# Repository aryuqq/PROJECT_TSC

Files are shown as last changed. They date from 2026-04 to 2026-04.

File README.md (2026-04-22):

# InkTime v6 - Advanced Open Source Smartwatch

InkTime v6 este un smartwatch open-source de inalta performanta, axat pe eficienta energetica extrema si un factor de forma compact. Aceasta revizie hardware aduce imbunatatiri majore pe partea de management al energiei, feedback haptic avansat si generarea tensiunilor pentru display direct pe placa de baza.

Acest repository contine fisierele de design hardware (Schematice, PCB layout, BOM) pentru faza **EVT (Engineering Validation Test)** a versiunii 6.

## 1. Diagrama Bloc a Sistemului

```mermaid
graph TD
    %% Power Management
    USB[Conector USB-C / ESD] -->|5V| CHG[IC Incarcare BQ25180]
    CHG --> BATT[Acumulator LiPo 3.7V]
    BATT --> FG[Fuel Gauge MAX17048]
    BATT --> DCDC[Buck-Boost RT6160]
    
    %% Core Power
    DCDC -.->|3.3V Stabilizat| MCU[SoC nRF52840]
    DCDC -.->|3.3V| PERIPH[Periferice]
    
    %% Core & Connectivity
    MCU <-->|I2C| FG
    
    %% Interfaces & Peripherals
    MCU <-->|SPI + Control| EINK[Display E-Paper 1.54]
    MCU -->|PWM/Control| EINK_DRV[Circuit E-Paper Drive On-Board]
    MCU <-->|I2C + INT| IMU[Accelerometru BMA423]
    MCU <-->|I2C + EN| HAPTIC[Driver Haptic DRV2605]
    HAPTIC --> VIB[Motor LRA/ERM]
    MCU -->|GPIO| BTN[3x Butoane Navigare]
```

## 2. Bill Of Materials (BOM)

Tabelul de mai jos contine circuitele integrate (IC-urile) principale folosite in designul placii. Lista completa se gaseste in fisierul .csv din folderul Manufacturing.
| Componenta | Rol in sistem | JLC Part # | Link Datasheet |
| :--- | :--- | :--- | :--- |
| **nRF52840-QIAA** | Microcontroller principal (BLE, Cortex-M4F) | C206001 | [Datasheet nRF52840](https://infocenter.nordicsemi.com/pdf/nRF52840_PS_v1.7.pdf) |
| **BQ25180YBGR** | IC Incarcare liniara avansata (Ultra-Low Iq) | N/A | [Datasheet BQ25180](https://www.ti.com/lit/ds/symlink/bq25180.pdf) |
| **RT6160AWSC** | Regulator DC/DC Buck-Boost 3.3V | C2836254 | [Datasheet RT6160](https://www.richtek.com/assets/product_file/RT6160A/DS6160A-02.pdf) |
| **MAX17048G+T10** | Fuel Gauge (Monitorizare Baterie prin I2C) | C113374 | [Datasheet MAX17048](https://www.analog.com/media/en/technical-documentation/data-sheets/MAX17048-MAX17049.pdf) |
| **BMA423** | Accelerometru Ultra-Low Power (Pedometer HW) | C283084 | [Datasheet BMA423](https://www.bosch-sensortec.com/media/boschsensortec/downloads/datasheets/bst-bma423-ds004.pdf) |
| **DRV2605YZFR** | Driver Haptic I2C (Generare vibratii complexe) | C63435 | [Datasheet DRV2605](https://www.ti.com/lit/ds/symlink/drv2605.pdf) |
| **USBLC6-2SC6Y** | Protectie ESD pe liniile de date si alimentare USB-C | C7519 | [Datasheet USBLC6](https://www.st.com/resource/en/datasheet/usblc6-2.pdf) |

## 3. Descrierea Functionalitatii Hardware
### Procesare si Conectivitate:

Inima ceasului InkTime este SoC-ul Nordic nRF52840. A fost ales datorita suportului nativ pentru Bluetooth 5.0 (BLE), esential pentru sincronizarea notificarilor cu telefonul mobil. Arhitectura ARM Cortex-M4F permite procesarea eficienta a algoritmilor senzorilor.
Managementul Consumului de Energie (Power Tree):

Fiind un dispozitiv wearable, constrangerile de baterie sunt critice. Sistemul energetic a fost complet reproiectat in v6.

Sistemul este alimentat de o baterie LiPo de mici dimensiuni (ex. 500mAh). Monitorizarea starii de incarcare (SoC) se face precis si fara consum mare de curent prin cipul MAX17048.

Incarcarea se face la 5V printr-un circuit BQ25180, un cip de top care permite controlul precis al pragurilor de incarcare.

Pentru a asigura tensiunea de 3.3V am folosit un convertor Buck-Boost RT6160 in loc de un LDO simplu. Acesta mentine 3.3V perfect stabil chiar si cand tensiunea bateriei scade, extragand maximum de energie din acumulator inainte de oprire.

### Periferice si Interfete:

Display-ul E-Ink: Comunica prin protocol SPI. Fata de versiunile anterioare, placa include propriul circuit de generare a tensiunilor inalte (E-Paper Drive On-Board cu inductor si mosfet), ceea ce reduce grosimea totala. Consuma 0mA pentru a mentine imaginea afisata.

Senzorii (IMU, Haptic, Fuel Gauge): Comunicatia se realizeaza pe o magistrala I2C partajata. BMA423 are un mod special de "step counter" hardware care poate trezi microcontroller-ul din sleep doar cand utilizatorul face un pas. Driver-ul DRV2605 ofera feedback haptic premium, descarcand procesorul de generarea semnalelor PWM.

## 4. Alocarea Pinilor nRF52840

Microcontroller-ul nRF52840 permite maparea flexibila a pinilor (orice functie digitala pe orice pin), lucru care a facilitat o rutare curata pe PCB.

| Pin nRF52840 | Nume Net / Functie | Justificare / Detalii |
| :--- | :--- | :--- |
| **P0.26 / P0.27** | `SDA/2.4C`, `SCL/2.4C` | Magistrala I2C principala (IMU, Haptic, Fuel Gauge, Charger). Contine rezistente de pull-up. |
| **P0.08 / P1.09** | `IMU_INT1`, `IMU_INT2` | Pini de intrerupere hardware. BMA423 trimite semnale aici pentru a trezi SoC-ul cand detecteaza miscare. |
| **P0.12** | `HAPTIC_EN` | Pin configurat ca iesire pentru a activa/dezactiva driver-ul de vibratii DRV2605. |
| **P0.04** | `EPD_CS` | Chip Select pentru activarea magistralei SPI a display-ului E-Paper. |
| **P0.13 - P0.15** | `MOSI`, `MISO`, `SCK` | Magistrala SPI hardware (rutata direct catre conectorul FPC de 24 pini). |
| **Diverse** | `SW_UP`, `SW_ENT`, `SW_DN` | Pini conectati la butoanele laterale, configurati cu retele RC (Hardware Debouncing) pentru o citire curata. |

## 5. Design Log & Integrare Mecanica
### Constructia PCB-ului:

Layout-ul este extrem de dens, folosind componente in capsule miniaturale (BGA si QFN). Rutarea respecta zona de "Keepout" a antenei de 2.4GHz, asigurand o bataie maxima a semnalului Bluetooth.
Interfete Fizice:

Conectorul USB Type-C este utilizat exclusiv pentru incarcare (5V) si a fost ranforsat mecanic. Debug-ul se face prin footprint-ul SWD standardizat (Tag-Connect TC2030).

## 6. Calcule Detaliate de Consum de Energie (Power Budget)

Dispozitivul este proiectat sa functioneze cu un acumulator LiPo de 500 mAh.
### Consum in Mod Sleep (Standby / System OFF)

    * nRF52840 (Sleep): ~1.5 uA

    * BMA423 (Low Power): ~2.0 uA

    * MAX17048 (Hibernate): ~0.5 uA

    * BQ25180 (Battery Discharge): ~10.0 uA

    * RT6160 (Quiescent): ~1.0 uA

    * Total Consum Sleep: ~15.0 uA (0.015 mA)

### Consum in Mod Activ (Actualizare Ecran / Bluetooth)

    * nRF52840 (CPU + TX RF): ~14.0 mA

    * E-Paper Drive (in timpul refresh-ului): ~8.0 mA

    * Total Consum Activ (varf): ~22.0 mA

### Estimarea Autonomiei

Presupunand un ciclu de utilizare cu 50 de treziri pe zi si o medie calculata de 0.15 mA consum hibrid:

500 mAh / 0.15 mA = 3333 ore = Aproximativ 138 de zile (peste 4 luni) teoretice cu o singura incarcare.

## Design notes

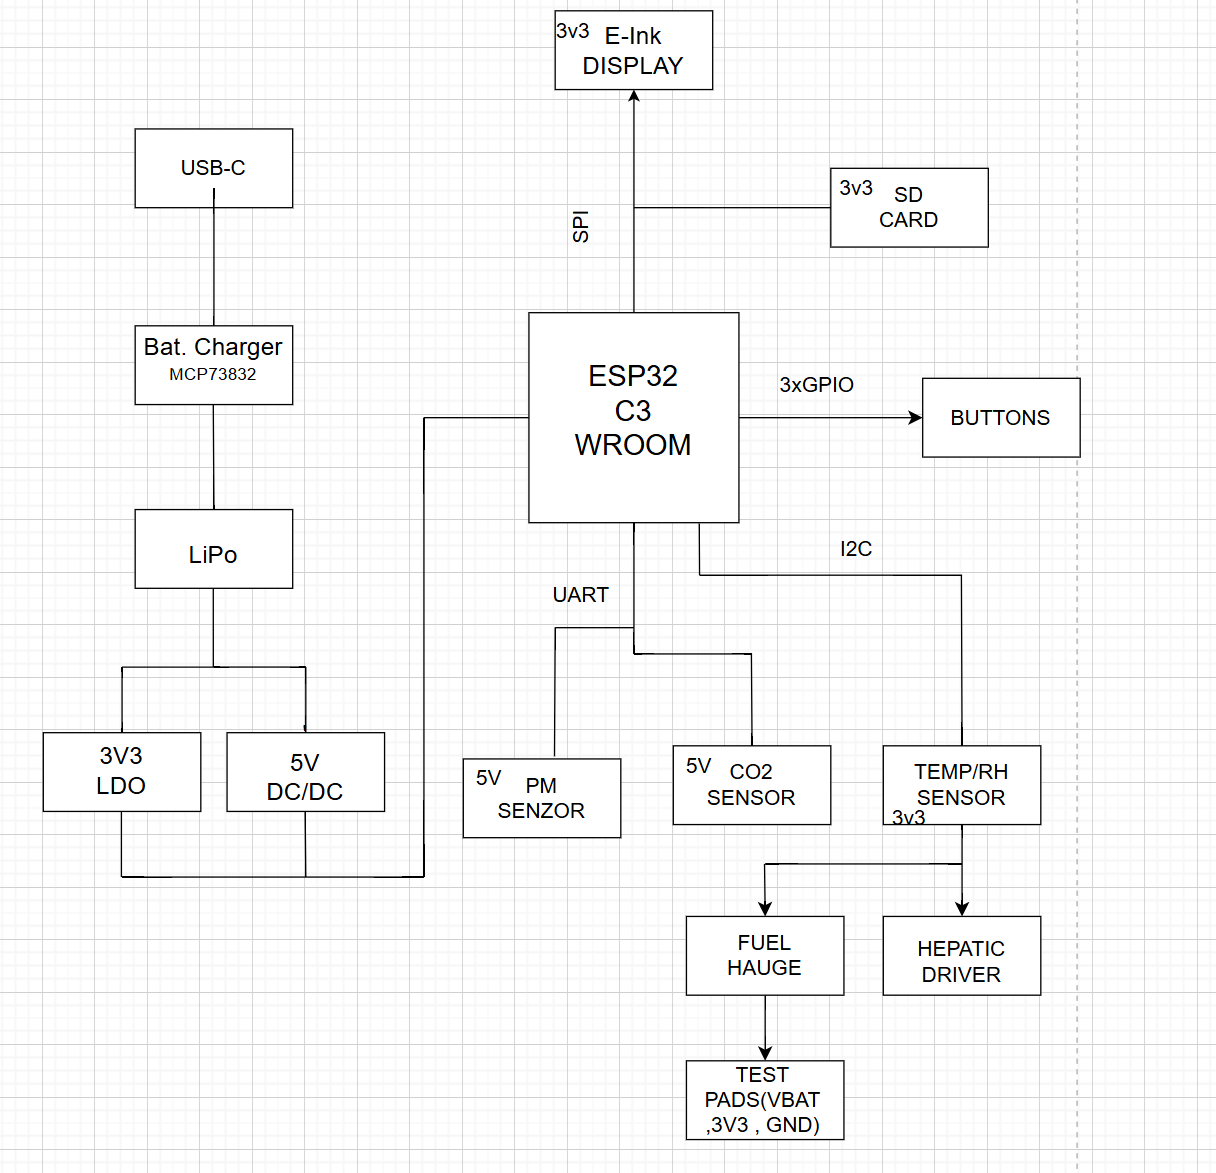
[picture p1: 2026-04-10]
Images/Diagram.png

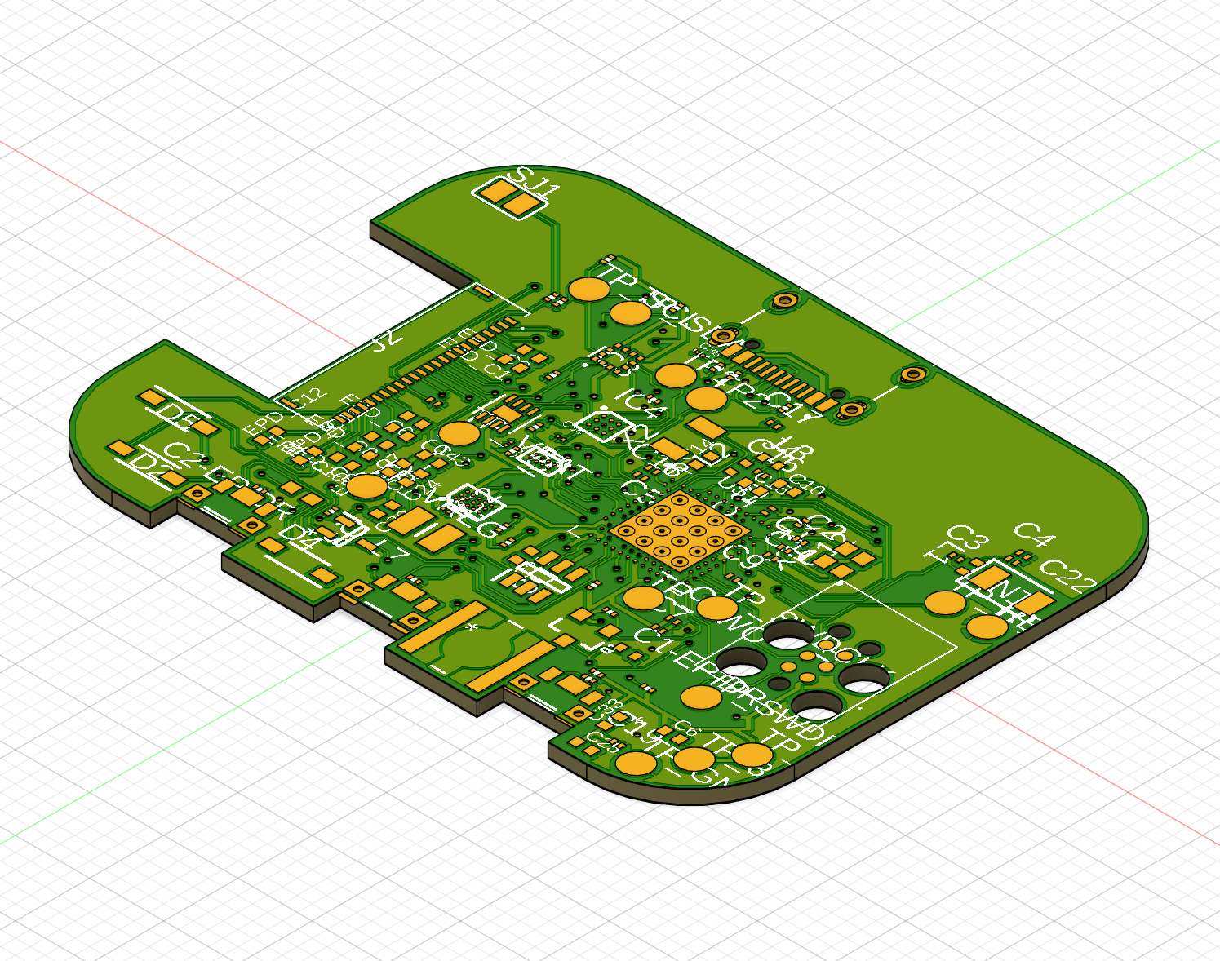
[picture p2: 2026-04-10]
Images/PCB3D.png

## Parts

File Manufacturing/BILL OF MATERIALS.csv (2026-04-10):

Reference Designators | Quantity | Description | Package | Value | Manufacturer | Manufacturer Part Number | Vendor | Vendor Part Number | Top/Bottom
 | 1 | PCB Board | Board
ANT1 | 1 | Antennas 2.45GHz ANTENNA | 2450AT18B100E_ANTC3216X140N | 2450AT18B100E_2450AT18B100E |  |  |  |  | Top
C1, C2, C17, C18 | 4 | Generic chip capacitor | NORDIC_NRF_3_RESC0201_L | 12pF |  |  |  |  | Top
C1-EP-DR | 1 | Generic chip capacitor | NORDIC_NRF_3_RESC0402_L | 10µF |  |  |  |  | Top
C2-EP-DR | 1 | Generic chip capacitor | NORDIC_NRF_3_RESC0603_L | 4.7µF/25V |  |  |  |  | Top
C3, C4 | 2 | Generic chip capacitor | NORDIC_NRF_3_RESC0201_L | 1pF |  |  |  |  | Top
C5, C7, C8, C12, C19 | 5 | Generic chip capacitor | NORDIC_NRF_3_RESC0201_L | 100nF |  |  |  |  | Top
C6, C14, C20, C21, C43 | 5 | 0402 (1005 Metric) | PERFECT_0402_0402 | 4.7µF |  |  |  |  | Top
C9 | 1 | Generic chip capacitor | NORDIC_NRF_3_RESC0201_L | 820pF N.C |  |  |  |  | Top
C10 | 1 | 0402 (1005 Metric) | PERFECT_0402_0402 | N.C |  |  |  |  | Top
C11 | 1 | Generic chip capacitor | NORDIC_NRF_3_RESC0201_L | 100pF |  |  |  |  | Top
C13, C22 | 2 | Generic chip capacitor | NORDIC_NRF_3_RESC0201_L | N.C |  |  |  |  | Top
C15 | 1 | 0402 (1005 Metric) | PERFECT_0402_0402 | 1.0µF |  |  |  |  | Top
C16 | 1 | Generic chip capacitor | NORDIC_NRF_3_RESC0201_L | 47nF |  |  |  |  | Top
C23, C37, C38 | 3 | Check availability | CAPC0201X13N | 1uF |  |  |  |  | Top
C24 | 1 | 0402 (1005 Metric) | PERFECT_0402_0402 | 10µF |  |  |  |  | Top
C25, C33 | 2 | 0402 (1005 Metric) | PERFECT_0402_0402 | 22µF |  |  |  |  | Top
C27, C42 | 2 | Check availability | GRM011R60J152KE01L_1_0201 | 0.1µF |  |  |  |  | Top
C29, C30, C31, C32 | 4 | Check availability | GRM011R60J152KE01L_1_0201 | 1µF |  |  |  |  | Top
C34 | 1 | Check availability | CAPC0201X13N | 0.1µF |  |  |  |  | Top
C39 | 1 | 0402 (1005 Metric) | PERFECT_0402_0402 | 10uF |  |  |  |  | Top
D2, D4, D5 | 3 | ON SEMICONDUCTOR - MBR0530 - DIODE, SCHOTTKY, 0.5A, 30V, SOD-123 | SOD3716X135N | MBR0530 |  |  |  |  | Top
D3 | 1 | Low Cap. ESD Protection Auto SOT-23-6 STMicroelectronics USBLC6-2SC6Y, Dual Uni-Directional TVS Diode Array, 6-Pin SOT-23 | SOT95P280X145-6N | USBLC6-2SC6Y |  |  |  |  | Top
EPD_C1, EPD_C2, EPD_C6, EPD_C7, EPD_C8, EPD_C9, EPD_C10, EPD_C11, EPD_C12 | 9 | 0402 (1005 Metric) | PERFECT_0402_0402 | 1uF/50V |  |  |  |  | Top
EPD_C5 | 1 | Generic chip capacitor | NORDIC_NRF_3_RESC0201_L | 0.1uF/50V |  |  |  |  | Top
IC1 | 1 | Charger IC Lithium Ion/Polymer, Lithium Iron Phosphate 8-DSBGA (1.6x1.1) | BQ25180YBGR_BGA8C40P2X4_100X155X50 | BQ25180YBGR_BQ25180YBGR |  |  |  |  | Top
IC2 | 1 | Buck-Boost Regulator Positive Output Step-Up/Step-Down I2C DC-DC Controller IC 15-WL-CSP (BSC) (1.4x2.3) | RT6160AWSC_BGA15C40P3X5_140X230X60 | RT6160AWSC_RT6160AWSC |  |  |  |  | Top
IC3 | 1 | Accelerometers Triaxial low-g 12bit Acceleration Sensor | BMA423_BMA423 | BMA423_BMA423 |  |  |  |  | Top
IC4 | 1 | Haptic Driver for ERM/LRA with Built-In Library and Smart Loop Architecture | DRV2605YZFR_BGA9C50P3X3_144X144X62 | DRV2605YZFR_DRV2605YZFR |  |  |  |  | Top
J1 | 1 | CABLE ADAPTER 6 POS | TC2030-IDC_TC2030IDC | TC2030-IDC_TC2030-IDC |  |  |  |  | Top
J2 | 1 | FFC & FPC Connectors 0.5mm FPC RA SMT Dual Contact 24Ckt | 503480-2400_5034802400 | 503480-2400_503480-2400 |  |  |  |  | Top
J4 | 1 | Check availability | KINGHELM_KH-TYPE-C-16P | KH-TYPE-C-16P |  |  |  |  | Top
L1 | 1 | Generic chip inductor | NORDIC_NRF_2_RESC0402_L | 3.9nH |  |  |  |  | Top
L2 | 1 | Generic chip inductor | NORDIC_NRF_2_RESC0402_L | 10µF |  |  |  |  | Top
L3 | 1 | Generic chip inductor | NORDIC_NRF_2_RESC0402_L | 15nH |  |  |  |  | Top
L5 | 1 |  | ESP32_C6_LIBRARY_2_IND_4828-WE-TPC_WRE | 68µH |  |  |  |  | Top
L7 | 1 | SMD / SMT Inductors (Coils), L=0.47?H, L x W x T : | MLP2016SR47MT0S1_INDC2016X100N | MLP2016SR47MT0S1_FTC252012SR47MBCA |  |  |  |  | Top
Q1 | 1 | P-channel MOSFETs | ESP32_WROVER_SPARKFUN-DISCRETESEMI_SOT23-3 | 20V/4.2A/52mΩ/1.4W |  |  |  |  | Top
Q3 | 1 | MOSFET N-Ch 30V 1.5A TrenchFET SC70 Vishay Si1308EDL-T1-GE3 N-channel MOSFET Transistor, 1.5 A, 30 V, 3-Pin SC-70 | SOT65P210X110-3N | SI1308EDL-T1-GE3 |  |  |  |  | Top
R_PWR_EPD, R1, R2_EP_DR, R5, R6, R9 | 6 | 7.68k 0201 Thin Film Surface Mount Fixed Resistor +/-0.5% 0.031W CPF0201D7K68C1 | CPF0201D7K68C1_0201 | 10K |  |  |  |  | Top
R_TYPE_SEL | 1 | 7.68k 0201 Thin Film Surface Mount Fixed Resistor +/-0.5% 0.031W CPF0201D7K68C1 | CPF0201D7K68C1_0201 | 2.2 |  |  |  |  | Top
R1_EP_DR | 1 | 7.68k 0201 Thin Film Surface Mount Fixed Resistor +/-0.5% 0.031W CPF0201D7K68C1 | CPF0201D7K68C1_0201 | 0.47 |  |  |  |  | Top
R1_USB, R2_USB | 2 | 7.68k 0201 Thin Film Surface Mount Fixed Resistor +/-0.5% 0.031W CPF0201D7K68C1 | CPF0201D7K68C1_0201 | 5K1 |  |  |  |  | Top
R2, R3, R4 | 3 | 7.68k 0201 Thin Film Surface Mount Fixed Resistor +/-0.5% 0.031W CPF0201D7K68C1 | CPF0201D7K68C1_0201 | 0 |  |  |  |  | Top
R17, R18 | 2 | 7.68k 0201 Thin Film Surface Mount Fixed Resistor +/-0.5% 0.031W CPF0201D7K68C1 | R0201 | 3K3 |  |  |  |  | Top
SJ1 | 1 | SMD solder JUMPER | JUMPER_SJ |  |  |  |  |  | Top
SW_DN, SW_ENT, SW_UP | 3 |  | SW_EVP-AKE31A_PAN | 2025-10-22_07-23-44_LIBRARY_EVP-AKE31ASW_EVP-AKE31A_PAN |  |  |  |  | Top
TP_3.3V, TP_3V3, TP_BAT_GND, TP_GND, TP_RESET, TP_SCL, TP_SDA, TP_SWDCLK, TP_SWDIO, TP_SWO, TP_VBAT, TP_VREG, TP1, TP2 | 14 | Test pad | HECTOR_WATCH_1_TP20R | HECTOR_WATCH_1_TPTP20R |  |  |  |  | Top
U$1 | 1 | nRF52840 | NORDIC_NRF_4_AQFN50P700X700X85_HS-74N | NORDIC_NRF_4_NRF52840_QF |  |  |  |  | Top
U3 | 1 | Check availability | SON50P200X200X80-9N | MAX17048G+T10 |  |  |  |  | Top
X1 | 1 |  | NORDIC_NRF_BT-XTAL_2016_N | 32MHz |  |  |  |  | Top
X2 | 1 |  | NORDIC_NRF_1_XTAL_3215_N | 32.768kHz |  |  |  |  | Top

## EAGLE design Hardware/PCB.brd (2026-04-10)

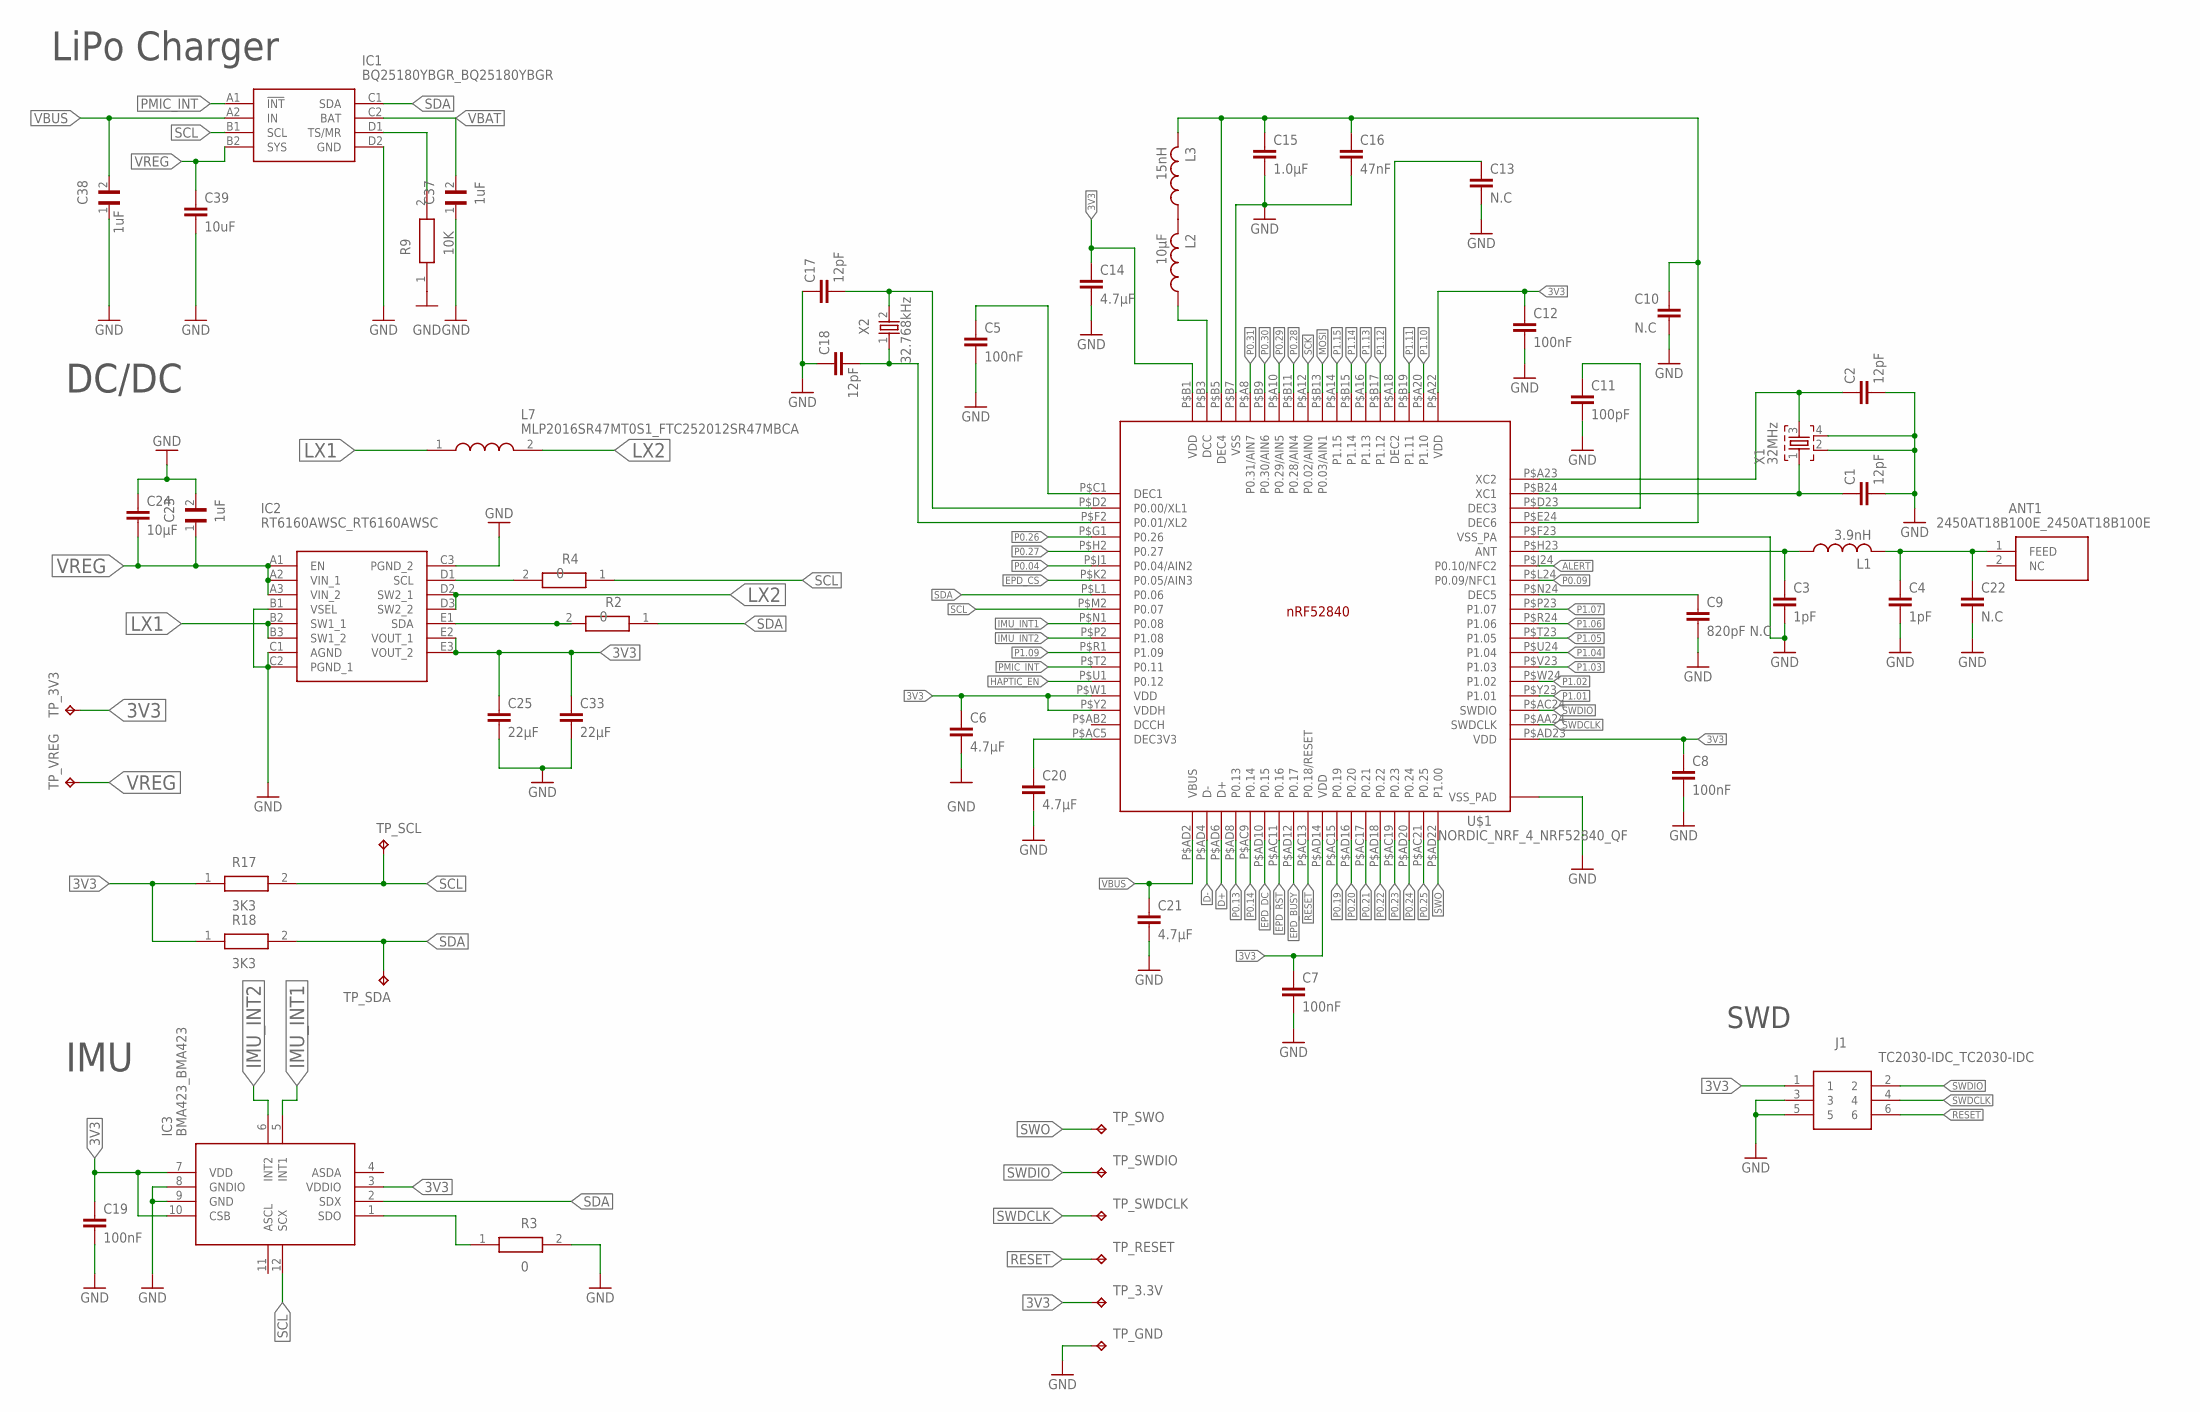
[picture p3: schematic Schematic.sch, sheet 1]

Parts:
ANT1: 2450AT18B100E_2450AT18B100E; 2450AT18B100E_ANTC3216X140N
C1, C2, C17, C18: 12pF; NORDIC_NRF_3_RESC0201_L
C3, C4: 1pF; NORDIC_NRF_3_RESC0201_L
C5, C7, C8, C12, C19: 100nF; NORDIC_NRF_3_RESC0201_L
C6, C14, C20, C21: 4.7µF; PERFECT_0402_0402
C9: 820pF N.C; NORDIC_NRF_3_RESC0201_L
C10: N.C; PERFECT_0402_0402
C11: 100pF; NORDIC_NRF_3_RESC0201_L
C13, C22: N.C; NORDIC_NRF_3_RESC0201_L
C15: 1.0µF; PERFECT_0402_0402
C16: 47nF; NORDIC_NRF_3_RESC0201_L
C23, C37, C38: 1uF; GRM011R60J152KE01L_2_CAPC0201X13N
C24: 10µF; PERFECT_0402_0402
C25, C33: 22µF; PERFECT_0402_0402
C39: 10uF; PERFECT_0402_0402
IC1: BQ25180YBGR_BQ25180YBGR; BQ25180YBGR_BGA8C40P2X4_100X155X50
IC2: RT6160AWSC_RT6160AWSC; RT6160AWSC_BGA15C40P3X5_140X230X60
IC3: BMA423_BMA423
J1: TC2030-IDC_TC2030-IDC; TC2030-IDC_TC2030IDC
L1: 3.9nH; NORDIC_NRF_2_RESC0402_L
L2: 10µF; NORDIC_NRF_2_RESC0402_L
L3: 15nH; NORDIC_NRF_2_RESC0402_L
L7: MLP2016SR47MT0S1_FTC252012SR47MBCA; MLP2016SR47MT0S1_INDC2016X100N
R2, R3, R4: 0; CPF0201D7K68C1_0201
R9: 10K; CPF0201D7K68C1_0201
R17, R18: 3K3; ERA-1AEB3401C_0201
TP_3.3V, TP_3V3: HECTOR_WATCH_1_TPTP20R; HECTOR_WATCH_1_TP20R
TP_GND: HECTOR_WATCH_1_TPTP20R; HECTOR_WATCH_1_TP20R
TP_RESET: HECTOR_WATCH_1_TPTP20R; HECTOR_WATCH_1_TP20R
TP_SCL: HECTOR_WATCH_1_TPTP20R; HECTOR_WATCH_1_TP20R
TP_SDA: HECTOR_WATCH_1_TPTP20R; HECTOR_WATCH_1_TP20R
TP_SWDCLK: HECTOR_WATCH_1_TPTP20R; HECTOR_WATCH_1_TP20R
TP_SWDIO: HECTOR_WATCH_1_TPTP20R; HECTOR_WATCH_1_TP20R
TP_SWO: HECTOR_WATCH_1_TPTP20R; HECTOR_WATCH_1_TP20R
TP_VREG: HECTOR_WATCH_1_TPTP20R; HECTOR_WATCH_1_TP20R
U$1: NORDIC_NRF_4_NRF52840_QF; NORDIC_NRF_4_AQFN50P700X700X85_HS-74N
X1: 32MHz; NORDIC_NRF_BT-XTAL_2016_N
X2: 32.768kHz; NORDIC_NRF_1_XTAL_3215_N

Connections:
3V3: C6.1, C7.1, C8.1, C12.1, C14.1, C19.1, C25.1, C33.1, IC2.E2 (VOUT_1), IC2.E3 (VOUT_2), IC3.3 (VDDIO), IC3.7 (VDD), IC3.10 (CSB), J1.1, R17.1, R18.1, TP_3.3V.TP, TP_3V3.TP, U$1.P$A22 (VDD), U$1.P$AD14 (VDD), U$1.P$AD23 (VDD), U$1.P$B1 (VDD), U$1.P$W1 (VDD), U$1.P$Y2 (VDDH); also elsewhere on the board
ALERT: U$1.P$J24 (P0.10/NFC2); also elsewhere on the board
D+: U$1.P$AD6 (D+); also elsewhere on the board
D-: U$1.P$AD4 (D-); also elsewhere on the board
EPD_BUSY: U$1.P$AD12 (P0.17); also elsewhere on the board
EPD_CS: U$1.P$K2 (P0.05/AIN3); also elsewhere on the board
EPD_DC: U$1.P$AD10 (P0.15); also elsewhere on the board
EPD_RST: U$1.P$AC11 (P0.16); also elsewhere on the board
GND: C1.2, C2.2, C3.2, C4.2, C5.2, C6.2, C7.2, C8.2, C9.2, C10.2, C11.2, C12.2, C13.2, C14.2, C15.2, C16.2, C17.1, C18.1, C19.2, C20.2, C21.2, C22.2, C23.2, C24.1, C25.2, C33.2, C37.1, C38.1, C39.2, IC1.D2 (GND), IC2.B1 (VSEL), IC2.C1 (AGND), IC2.C2 (PGND_1), IC2.C3 (PGND_2), IC3.8 (GNDIO), IC3.9 (GND), J1.3, J1.5, R3.2, R9.1, TP_GND.TP, U$1.P$74 (VSS_PAD), U$1.P$75 (VSS_PAD), U$1.P$76 (VSS_PAD), U$1.P$77 (VSS_PAD), U$1.P$78 (VSS_PAD), U$1.P$79 (VSS_PAD), U$1.P$80 (VSS_PAD), U$1.P$81 (VSS_PAD), U$1.P$82 (VSS_PAD), U$1.P$83 (VSS_PAD), U$1.P$84 (VSS_PAD), U$1.P$85 (VSS_PAD), U$1.P$86 (VSS_PAD), U$1.P$87 (VSS_PAD), U$1.P$88 (VSS_PAD), U$1.P$89 (VSS_PAD), U$1.P$90 (VSS_PAD), U$1.P$B7 (VSS), U$1.P$F23 (VSS_PA), X1.2, X1.4; also elsewhere on the board
HAPTIC_EN: U$1.P$U1 (P0.12); also elsewhere on the board
IMU_INT1: IC3.5 (INT1), U$1.P$N1 (P0.08)
IMU_INT2: IC3.6 (INT2), U$1.P$P2 (P1.08)
LX1: IC2.B2 (SW1_1), IC2.B3 (SW1_2), L7.1
LX2: IC2.D2 (SW2_1), IC2.D3 (SW2_2), L7.2
MOSI: U$1.P$B13 (P0.03/AIN1); also elsewhere on the board
unnamed: L2.2, L3.1
unnamed: L2.1, U$1.P$B3 (DCC)
unnamed: IC1.D1 (TS/MR), R9.2
unnamed: IC3.1 (SDO), R3.1
unnamed: IC2.D1 (SCL), R4.2
unnamed: C10.1, C15.1, C16.1, L3.2, U$1.P$B5 (DEC4), U$1.P$E24 (DEC6)
unnamed: IC2.E1 (SDA), R2.2
unnamed: C13.1, U$1.P$A18 (DEC2)
unnamed: C11.1, U$1.P$D23 (DEC3)
unnamed: C2.1, U$1.P$A23 (XC2), X1.3
unnamed: C1.1, U$1.P$B24 (XC1), X1.1
unnamed: C3.1, L1.1, U$1.P$H23 (ANT)
unnamed: ANT1.1 (FEED), C4.1, C22.1, L1.2
unnamed: C9.1, U$1.P$N24 (DEC5)
unnamed: C20.1, U$1.P$AC5 (DEC3V3)
unnamed: C5.1, U$1.P$C1 (DEC1)
unnamed: C17.2, U$1.P$D2 (P0.00/XL1), X2.2
unnamed: C18.2, U$1.P$F2 (P0.01/XL2), X2.1
P0.04: U$1.P$J1 (P0.04/AIN2)
P0.09: U$1.P$L24 (P0.09/NFC1)
P0.13: U$1.P$AD8 (P0.13); also elsewhere on the board
P0.14: U$1.P$AC9 (P0.14); also elsewhere on the board
P0.19: U$1.P$AC15 (P0.19)
P0.20: U$1.P$AD16 (P0.20)
P0.21: U$1.P$AC17 (P0.21)
P0.22: U$1.P$AD18 (P0.22)
P0.23: U$1.P$AC19 (P0.23)
P0.24: U$1.P$AD20 (P0.24)
P0.25: U$1.P$AC21 (P0.25)
P0.26: U$1.P$G1 (P0.26)
P0.27: U$1.P$H2 (P0.27)
P0.28: U$1.P$B11 (P0.28/AIN4)
P0.29: U$1.P$A10 (P0.29/AIN5)
P0.30: U$1.P$B9 (P0.30/AIN6)
P0.31: U$1.P$A8 (P0.31/AIN7)
P1.01: U$1.P$Y23 (P1.01); also elsewhere on the board
P1.02: U$1.P$W24 (P1.02); also elsewhere on the board
P1.03: U$1.P$V23 (P1.03)
P1.04: U$1.P$U24 (P1.04)
P1.05: U$1.P$T23 (P1.05)
P1.06: U$1.P$R24 (P1.06)
P1.07: U$1.P$P23 (P1.07)
P1.09: U$1.P$R1 (P1.09)
P1.10: U$1.P$A20 (P1.10)
P1.11: U$1.P$B19 (P1.11)
P1.12: U$1.P$B17 (P1.12)
P1.13: U$1.P$A16 (P1.13)
P1.14: U$1.P$B15 (P1.14)
P1.15: U$1.P$A14 (P1.15)
PMIC_INT: IC1.A1 (!INT), U$1.P$T2 (P0.11)
RESET: J1.6, TP_RESET.TP, U$1.P$AC13 (P0.18/RESET)
SCK: U$1.P$A12 (P0.02/AIN0); also elsewhere on the board
SCL: IC1.B1 (SCL), IC3.12 (SCX), R4.1, R17.2, TP_SCL.TP, U$1.P$M2 (P0.07); also elsewhere on the board
SDA: IC1.C1 (SDA), IC3.2 (SDX), R2.1, R18.2, TP_SDA.TP, U$1.P$L1 (P0.06); also elsewhere on the board
SWDCLK: J1.4, TP_SWDCLK.TP, U$1.P$AA24 (SWDCLK)
SWDIO: J1.2, TP_SWDIO.TP, U$1.P$AC24 (SWDIO)
SWO: TP_SWO.TP, U$1.P$AD22 (P1.00)
VBAT: C37.2, IC1.C2 (BAT); also elsewhere on the board
VBUS: C21.1, C38.2, IC1.A2 (IN), U$1.P$AD2 (VBUS); also elsewhere on the board
VREG: C23.1, C24.2, C39.1, IC1.B2 (SYS), IC2.A1 (EN), IC2.A2 (VIN_1), IC2.A3 (VIN_2), TP_VREG.TP

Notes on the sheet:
LiPo Charger
DC/DC
IMU
SWD

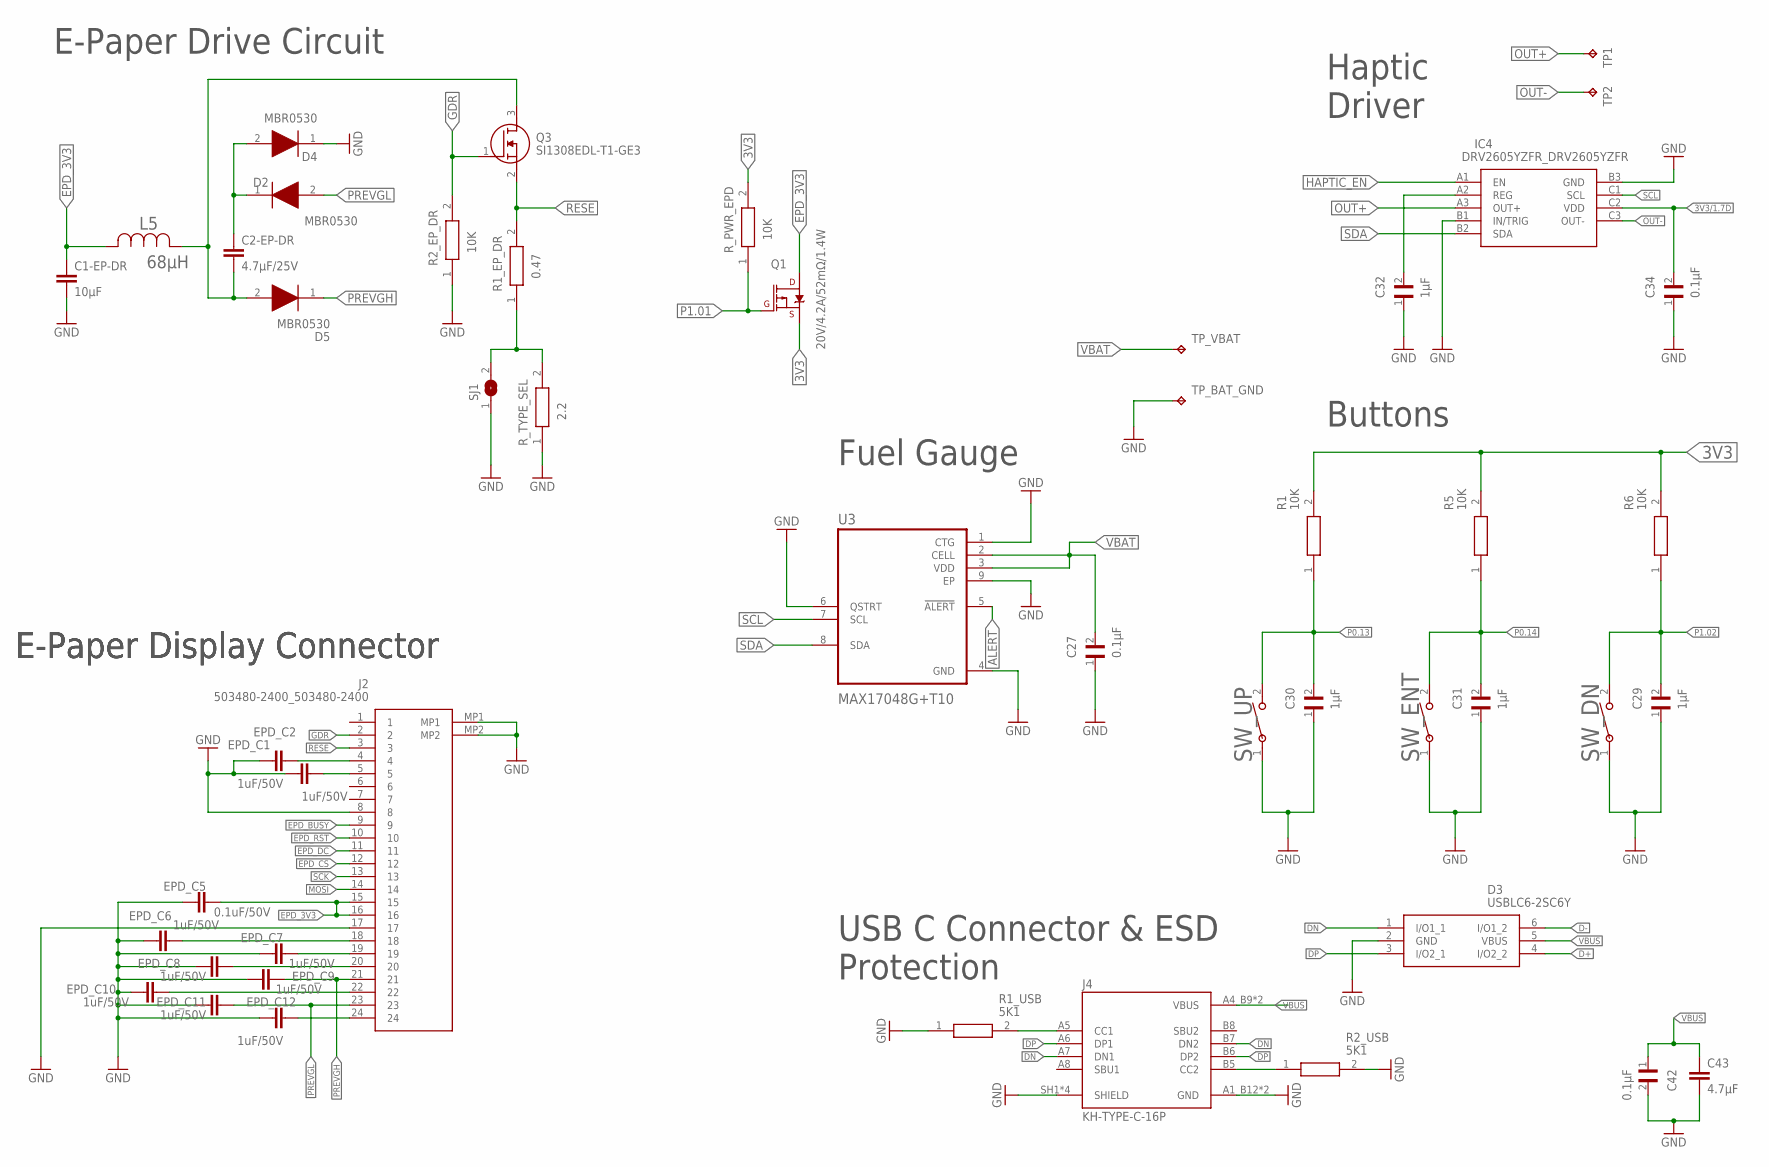
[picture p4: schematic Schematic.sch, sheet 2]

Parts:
C1-EP-DR: 10µF; NORDIC_NRF_3_RESC0402_L
C2-EP-DR: 4.7µF/25V; NORDIC_NRF_3_RESC0603_L
C27, C42: 0.1µF; GRM011R60J152KE01L_1_0201
C29, C30, C31, C32: 1µF; GRM011R60J152KE01L_1_0201
C34: 0.1µF; GRM011R60J152KE01L_2_CAPC0201X13N
C43: 4.7µF; PERFECT_0402_0402
D2, D4, D5: MBR0530; ESP32_C6_LIBRARY_5_SOD3716X135N
D3: USBLC6-2SC6Y; ESP32_C6_LIBRARY_3_SOT95P280X145-6N
EPD_C1, EPD_C2, EPD_C6, EPD_C7, EPD_C8, EPD_C9, EPD_C10, EPD_C11, EPD_C12: 1uF/50V; PERFECT_0402_0402
EPD_C5: 0.1uF/50V; NORDIC_NRF_3_RESC0201_L
IC4: DRV2605YZFR_DRV2605YZFR; DRV2605YZFR_BGA9C50P3X3_144X144X62
J2: 503480-2400_503480-2400; 503480-2400_5034802400
J4: KH-TYPE-C-16P; KH-TYPE-C-16P_KINGHELM_KH-TYPE-C-16P
L5: 68µH; ESP32_C6_LIBRARY_2_IND_4828-WE-TPC_WRE
Q1: 20V/4.2A/52mΩ/1.4W; ESP32_C6_LIBRARY_4_ESP32_C6_LIBRARY_4_ESP32_C6_LIBRARY_4_ES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
Q3: SI1308EDL-T1-GE3; ESP32_C6_LIBRARY_6_SOT65P210X110-3N
R1, R2_EP_DR, R5, R6: 10K; CPF0201D7K68C1_0201
R1_EP_DR: 0.47; CPF0201D7K68C1_0201
R1_USB, R2_USB: 5K1; CPF0201D7K68C1_0201
R_PWR_EPD: 10K; CPF0201D7K68C1_0201
R_TYPE_SEL: 2.2; CPF0201D7K68C1_0201
SJ1: ESP32_C6_LIBRARY_7_JUMPER_SJ
SW_DN: 2025-10-22_07-23-44_LIBRARY_EVP-AKE31ASW_EVP-AKE3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; 2025-10-22_07-23-44_LIBRARY_SW_EVP-AKE31A_PAN
SW_ENT: 2025-10-22_07-23-44_LIBRARY_EVP-AKE31ASW_EVP-AKE3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; 2025-10-22_07-23-44_LIBRARY_SW_EVP-AKE31A_PAN
SW_UP: 2025-10-22_07-23-44_LIBRARY_EVP-AKE31ASW_EVP-AKE3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; 2025-10-22_07-23-44_LIBRARY_SW_EVP-AKE31A_PAN
TP1, TP2: HECTOR_WATCH_1_TPTP20R; HECTOR_WATCH_1_TP20R
TP_BAT_GND: HECTOR_WATCH_1_TPTP20R; HECTOR_WATCH_1_TP20R
TP_VBAT: HECTOR_WATCH_1_TPTP20R; HECTOR_WATCH_1_TP20R
U3: MAX17048G+T10; ESP32_C6_LIBRARY_SON50P200X200X80-9N

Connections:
3V3: Q1.2 (S), R1.2, R5.2, R6.2, R_PWR_EPD.2; also elsewhere on the board
3V3/1.7D: C34.2, IC4.C2 (VDD)
ALERT: U3.5 (!ALERT); also elsewhere on the board
D+: D3.4 (I/O2_2); also elsewhere on the board
D-: D3.6 (I/O1_2); also elsewhere on the board
DN: D3.1 (I/O1_1), J4.A7 (DN1), J4.B7 (DN2)
DP: D3.3 (I/O2_1), J4.A6 (DP1), J4.B6 (DP2)
EPD_3V3: C1-EP-DR.1, EPD_C5.2, J2.15, J2.16, L5.2, Q1.3 (D)
EPD_BUSY: J2.9; also elsewhere on the board
EPD_CS: J2.12; also elsewhere on the board
EPD_DC: J2.11; also elsewhere on the board
EPD_RST: J2.10; also elsewhere on the board
GDR: J2.2, Q3.1 (G), R2_EP_DR.2
GND: C1-EP-DR.2, C27.1, C29.1, C30.1, C31.1, C32.1, C34.1, C42.2, C43.2, D3.2 (GND), D4.1 (K), EPD_C1.1, EPD_C2.1, EPD_C5.1, EPD_C6.1, EPD_C7.1, EPD_C8.1, EPD_C9.1, EPD_C10.1, EPD_C11.1, EPD_C12.1, IC4.B1 (IN/TRIG), IC4.B3 (GND), J2.8, J2.17, J2.MP1, J2.MP2, J4.A1_B12 (GND), J4.A12_B1 (GND), J4.SH1 (SHIELD), J4.SH2 (SHIELD), J4.SH3 (SHIELD), J4.SH4 (SHIELD), R1_USB.1, R2_EP_DR.1, R2_USB.2, R_TYPE_SEL.1, SJ1.1, SW_DN.1, SW_ENT.1, SW_UP.1, TP_BAT_GND.TP, U3.1 (CTG), U3.4 (GND), U3.6 (QSTRT), U3.9 (EP); also elsewhere on the board
HAPTIC_EN: IC4.A1 (EN); also elsewhere on the board
MOSI: J2.14; also elsewhere on the board
unnamed: EPD_C1.2, J2.5
unnamed: C2-EP-DR.2, D5.2 (A), L5.1, Q3.3 (D)
unnamed: EPD_C2.2, J2.4
unnamed: C32.2, IC4.A2 (REG)
unnamed: C2-EP-DR.1, D2.1 (K), D4.2 (A)
unnamed: J4.B5 (CC2), R2_USB.1
unnamed: J4.A5 (CC1), R1_USB.2
unnamed: R1_EP_DR.1, R_TYPE_SEL.2, SJ1.2
unnamed: EPD_C6.2, J2.18
unnamed: EPD_C7.2, J2.19
unnamed: EPD_C8.2, J2.20
unnamed: EPD_C10.2, J2.22
unnamed: EPD_C12.2, J2.24
OUT+: IC4.A3 (OUT+), TP1.TP
OUT-: IC4.C3 (OUT-), TP2.TP
P0.13: C30.2, R1.1, SW_UP.2; also elsewhere on the board
P0.14: C31.2, R5.1, SW_ENT.2; also elsewhere on the board
P1.01: Q1.1 (G), R_PWR_EPD.1; also elsewhere on the board
P1.02: C29.2, R6.1, SW_DN.2; also elsewhere on the board
PREVGH: D5.1 (K), EPD_C9.2, J2.21
PREVGL: D2.2 (A), EPD_C11.2, J2.23
RESE: J2.3, Q3.2 (S), R1_EP_DR.2
SCK: J2.13; also elsewhere on the board
SCL: IC4.C1 (SCL), U3.7 (SCL); also elsewhere on the board
SDA: IC4.B2 (SDA), U3.8 (SDA); also elsewhere on the board
VBAT: C27.2, TP_VBAT.TP, U3.2 (CELL), U3.3 (VDD); also elsewhere on the board
VBUS: C42.1, C43.1, D3.5 (VBUS), J4.A4_B9 (VBUS), J4.A9_B4 (VBUS); also elsewhere on the board

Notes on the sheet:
Haptic Driver
Fuel Gauge
Buttons
USB C Connector & ESD Protection
E-Paper Display Connector
E-Paper Drive Circuit

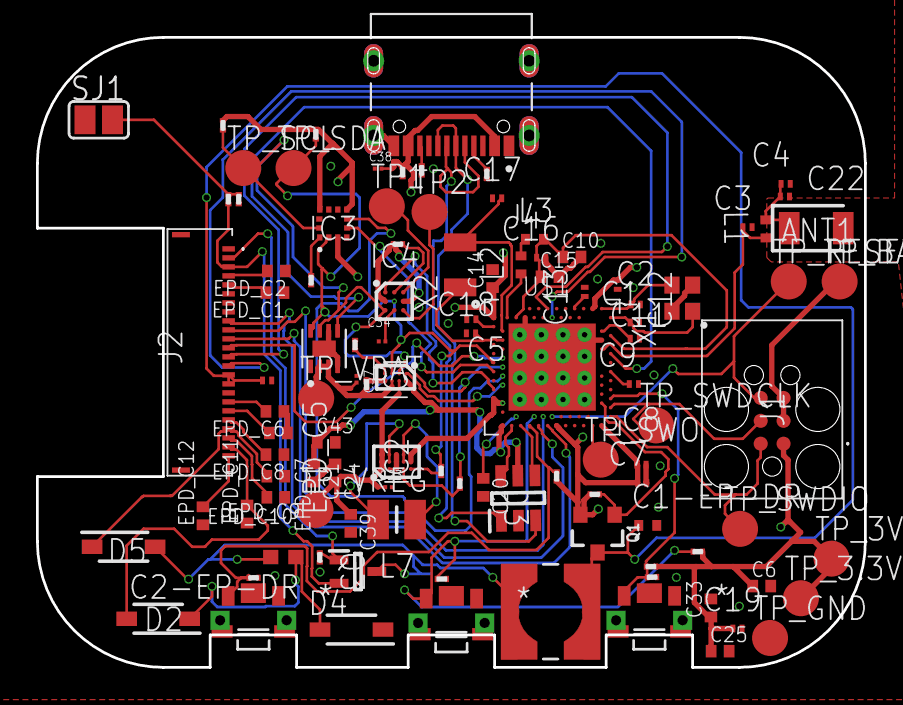
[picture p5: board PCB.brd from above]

Board: 4 copper layers, 46.0 x 35.0 mm, 105 parts (0 on the bottom side), 71 nets.

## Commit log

2026-04-10 README with project details
    Added notes about component modifications and wire thickness adjustments to avoid overlaps.
2026-04-17 Added new updates
    [Schematic.sch]
2026-04-22 README with project details
    Updated the README to include detailed information about the InkTime v6 smartwatch, including hardware functionality, power management, and component specifications.

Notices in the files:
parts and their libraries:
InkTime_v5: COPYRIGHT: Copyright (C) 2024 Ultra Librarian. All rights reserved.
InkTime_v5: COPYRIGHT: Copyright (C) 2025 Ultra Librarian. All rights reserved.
